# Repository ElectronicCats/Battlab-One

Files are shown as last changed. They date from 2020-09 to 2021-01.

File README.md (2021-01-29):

# BattLab-One
The BattLab-One estimates the battery life of your IOT project using the DUT cutoff voltage, battery state of charge data, event duration, and captured active and sleep event current profiles.

## Main characteristics 

- Captures both active event and sleep mode current

- MSP430 microcontroller based device that simulates standard batteries for Li-Ion, LiFePO4, Alkaline, NiMh, NiCd

- Provides voltages of 1.2V, 1.5V, 2.4V, 3.0V, 3.2, 3.6V, 3.7V, 4.5V at up to 450 mA.

- Trigger input to capture firmware states and their impact on overall battery life

- 1kHz Sample rate, 16 bit delta-sigma ADC

- Long active event capture duration from seconds to hours

- Extremely low burden voltage across all ranges (BattLab-One provides PSU output)

- Provides “what-if” optimization by letting you change your battery, current profiles, active and sleep duration as well as cutoff voltage

- Features the ability to save profiles so you can compare your DUT current profiles

- Interactive/detailed active current plot so you can look for anomalies and identify performance

## Archives
  - Battlab-One Quick Start Guide

  - BattLab_One_Production_Rev_A.py - Python Application Code for Production version 1.01

  - Production_Rev_A.sch - Schematic in Kicad

  - Production_Rev_A.kicad_pcb- PCB Layout in Kicad 

  - MSP430Firmware.c - Firmware code for the MSP430 for Production Version 1.01

  - BOM_Production_Rev_A - Bill of Materials for Battlab-One Production Rev A

  - 98-bluebird-labs.rules - Linux udev rules for Battlab-One

  See more at www.bluebird-labs.com

## Development

This project uses pipenv to take care of setting up a virtual environment as well as managing the dependencies needed.

1. Install pipenv as describe here https://pypi.org/project/pipenv/
2. Start a terminal and change to the root folder of this project.
3. Run pipenv to setup the environment: `pipenv install --dev`
4. Start the pipenv shell: `pipenv shell`
5. Start the application: `python BattLab_One_V1.0.6.py`

## License 

OpenSourceLicense

Electronic Cats invests time and resources providing this open source design, please support Electronic Cats and open-source hardware by purchasing products from Electronic Cats!

Designed by Bluebird Labs LLC

KiCad version Electronic Cats.

Electronic Cats is a registered trademark, please do not use if you sell these PCBs.

January 2021

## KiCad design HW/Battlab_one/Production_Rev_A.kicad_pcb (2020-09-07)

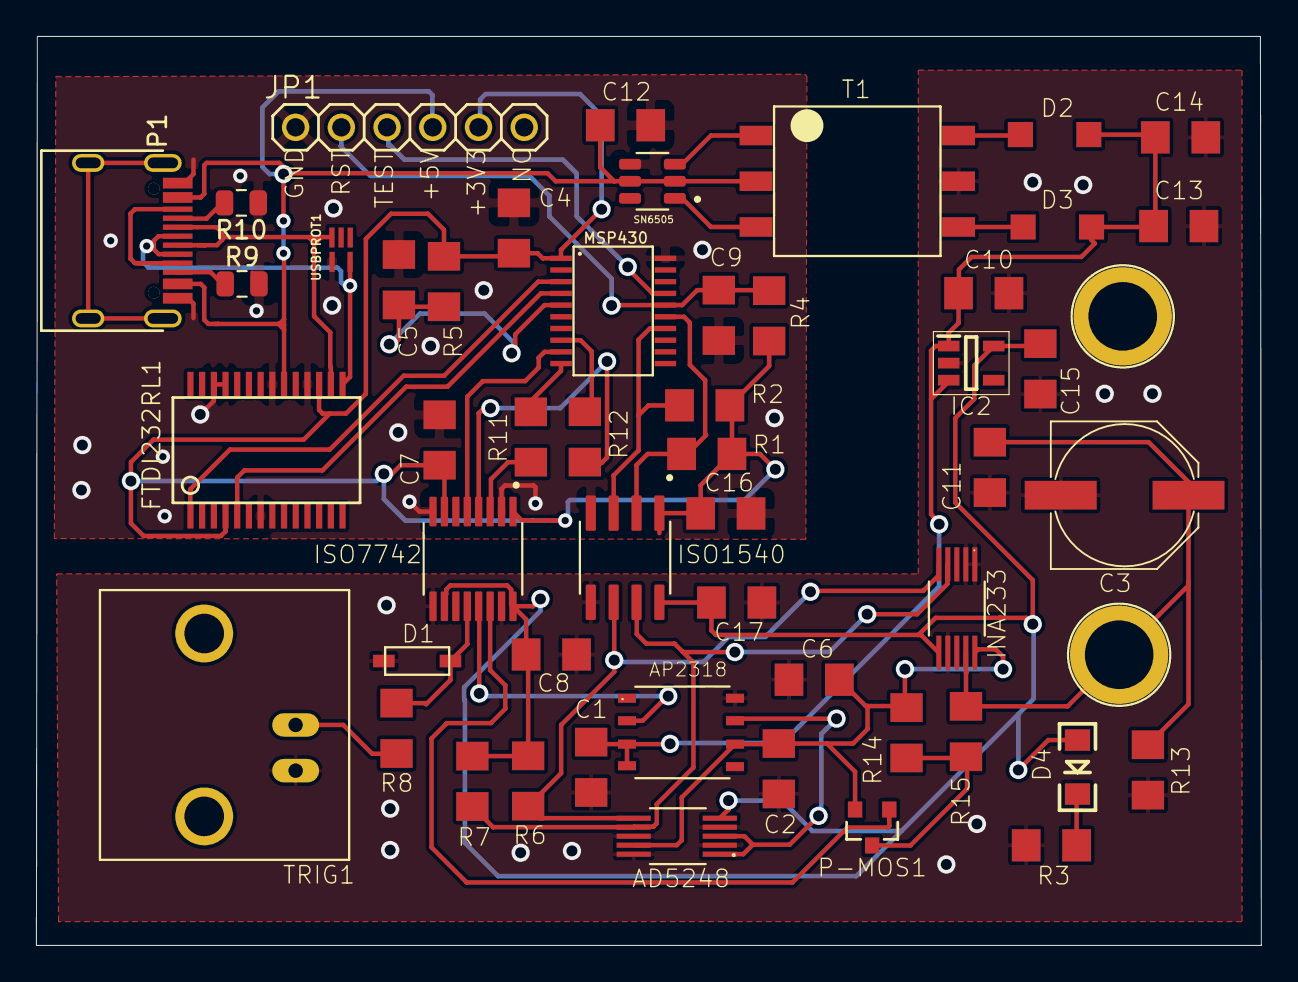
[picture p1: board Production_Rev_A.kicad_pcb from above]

Board: 2 copper layers, 68.1 x 50.5 mm, 53 parts (0 on the bottom side), 37 nets.

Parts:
AD5248: 100K; MSOP-10
AP2318: AP2318; SOIC-8
C1, C4, C10: 1uF; 1206
C2, C6, C15: 2.2uF; 1206
C3: 1000uF; PANASONIC_F
C5: .1uF; 1206
C7, C8, C11, C14, C16, C17: 0.1uF; 1206
C9: 1nF; 1206
C12, C13: 10uF; 1206
D1: DIODESOD-123; SOD-123
D2, D3: MBR0520LT1G; SOD3716X117(SOD-123)
D4: BLUE; LED-1206
FTDI232RL1: FT232RL; SSOP28DB
IC2: MIC5225-5.0YM5-TR; SOT95P280X130-5N
INA233: INA233; VSSOP-10
ISO1540: ISO1540; SOIC127P600X175-8N
ISO7742: ISO7742DBQ; SOP63P599X175-16N
J1, J3: BANANA_CONN
JP1: PINHD-1X6; 1X06
MSP430: MSP430; PW20
P1: USB_C_Plug; C393939
P-MOS1: P-MOSFET; SOT23-3
R1, R2, R6, R7: 10K; 1206
R3: 470; 1206
R4, R5: 47K; 1206
R8, R14: 100; 1206
R9, R10: 5.1K; R_0805_2012Metric
R11, R12: 220; 1206
R13: 100k; 1206
R15: 0.1; 1206
SN6505: SN6505; SOT95P280X145-6N
T1: 750315371; TOR-6P-HT4_SMT_6PIN_(1201)
TRIG1: BNCPTH; BNC
USBPROT1: TPD2E2U06DRLR; SOT50P160X60-5N

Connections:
/D+: FTDI232RL1.15, P1.A6, USBPROT1.5
/D-: FTDI232RL1.16, P1.A7, USBPROT1.3
/VBUS: C12.1, FTDI232RL1.20, JP1.3, P1.A4, SN6505.2, SN6505.5, T1.2
GND: C4.1, C5.1, C7.1, C9.1, C12.2, C16.2, FTDI232RL1.7, FTDI232RL1.18, FTDI232RL1.21, FTDI232RL1.25, FTDI232RL1.26, ISO1540.4, ISO7742.2, ISO7742.8, JP1.6, MSP430.20, P1.A1, R9.2, R10.1, SN6505.4, USBPROT1.4
GND1: AD5248.2, AD5248.4, AD5248.8, AD5248.10, AP2318.8, C1.1, C2.2, C3.-, C6.2, C8.2, C10.2, C11.1, C13.2, C14.2, C15.2, C17.2, D1.A, IC2.2, INA233.1, INA233.2, INA233.7, ISO1540.5, ISO7742.9, ISO7742.15, J3.P$1, R3.1, R13.2, T1.5, TRIG1.GND
unnamed: AD5248.1, AD5248.3, AP2318.7
unnamed: AD5248.5, C8.1, C15.1, C17.1, D4.A, IC2.5, INA233.6, ISO1540.8, ISO7742.10, ISO7742.16, R6.1, R7.1
unnamed: AD5248.6, INA233.5, ISO1540.6, R6.2
unnamed: AD5248.7, INA233.4, ISO1540.7, R7.2
unnamed: AD5248.9, AP2318.6, C2.1, C6.1, INA233.10, P-MOS1.2, R14.1
unnamed: AP2318.2, ISO7742.13
unnamed: AP2318.3, AP2318.4, C1.2, C10.1, C13.1, C14.1, D2.1, D3.1, IC2.1, IC2.3
unnamed: C5.2, MSP430.5, R5.1
unnamed: C9.2, JP1.5, MSP430.16, R4.2
unnamed: C3.+, C11.2, INA233.9, J1.P$1, R13.1, R15.2
unnamed: C4.2, C7.2, C16.1, FTDI232RL1.4, FTDI232RL1.17, ISO1540.1, ISO7742.1, ISO7742.7, JP1.2, MSP430.1, R1.2, R2.2, R4.1, R5.2
unnamed: D1.C, ISO7742.12, R8.2
unnamed: D2.2, T1.6
unnamed: D3.2, T1.4
unnamed: D4.C, R3.2
unnamed: FTDI232RL1.1, MSP430.3
unnamed: FTDI232RL1.5, MSP430.4
unnamed: ISO1540.2, MSP430.15, R1.1
unnamed: ISO1540.3, MSP430.14, R2.1
unnamed: ISO7742.3, R11.2
unnamed: ISO7742.4, R12.2
unnamed: ISO7742.5, MSP430.9
unnamed: ISO7742.14, P-MOS1.1
unnamed: JP1.4, MSP430.17
unnamed: MSP430.8, R12.1
unnamed: MSP430.10, R11.1
unnamed: P1.A5, R10.2
unnamed: P1.B5, R9.1
unnamed: P-MOS1.3, R14.2, R15.1
unnamed: R8.1, TRIG1.S
unnamed: SN6505.1, T1.3
unnamed: SN6505.3, T1.1

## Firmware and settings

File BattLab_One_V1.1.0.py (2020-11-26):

#################################################################################
##   MSP430G2xx3 based BattLab-One Production Version 1.01
##
##   Doug Peters
##   Bluebird Labs LLC.
##   www.bluebird-labs.com
##   February 2019
##   Built with CCS V7.0
##
##   Copyright (c) 2020, Bluebird Labs LLC
##   All rights reserved.
##
##   Redistribution and use in source and binary forms, with or without
##   modification, are permitted provided that the following conditions
##   are met:
##
##   * Redistributions of source code must retain the above copyright
##     notice, this list of conditions and the following disclaimer.
##
##   * Redistributions in binary form must reproduce the above copyright
##     notice, this list of conditions and the following disclaimer in the
##     documentation and/or other materials provided with the distribution.
##
##   * Neither the name of Bluebird Labs LLC nor the names of
##     its contributors may be used to endorse or promote products derived
##     from this software without specific prior written permission.
##
##  THIS SOFTWARE IS PROVIDED BY THE COPYRIGHT HOLDERS AND CONTRIBUTORS "AS IS"
##  AND ANY EXPRESS OR IMPLIED WARRANTIES, INCLUDING, BUT NOT LIMITED TO,
##  THE IMPLIED WARRANTIES OF MERCHANTABILITY AND FITNESS FOR A PARTICULAR
##  PURPOSE ARE DISCLAIMED. IN NO EVENT SHALL THE COPYRIGHT OWNER OR
##  CONTRIBUTORS BE LIABLE FOR ANY DIRECT, INDIRECT, INCIDENTAL, SPECIAL,
##  EXEMPLARY, OR CONSEQUENTIAL DAMAGES (INCLUDING, BUT NOT LIMITED TO,
##  PROCUREMENT OF SUBSTITUTE GOODS OR SERVICES; LOSS OF USE, DATA, OR PROFITS;
##  OR BUSINESS INTERRUPTION) HOWEVER CAUSED AND ON ANY THEORY OF LIABILITY,
##  WHETHER IN CONTRACT, STRICT LIABILITY, OR TORT (INCLUDING NEGLIGENCE OR
##  OTHERWISE) ARISING IN ANY WAY OUT OF THE USE OF THIS SOFTWARE,
##  EVEN IF ADVISED OF THE POSSIBILITY OF SUCH DAMAGE.
##
#################################################################################

import tkinter as tk
from tkinter import ttk
from tkinter import *
import csv
from csv import reader
import time
import datetime
import serial
import serial.tools.list_ports
from serial.tools import list_ports
import matplotlib
from matplotlib.widgets import Cursor
import matplotlib.pyplot as plt
import platform
from tkinter import colorchooser
from tkinter import font
import os
import pkg_resources.py2_warn
from tkinter import messagebox
from tkinter import filedialog
import webbrowser

matplotlib.use('TkAgg')

#from matplotlib.backends.backend_tkagg import FigureCanvasTkAgg, NavigationToolbar2TkAgg
from matplotlib.backends.backend_tkagg import FigureCanvasTkAgg, NavigationToolbar2Tk
from matplotlib.figure import Figure

#################################################################################    
###     SETUP ROOT, FRAMES, & MATPLOTLIB CANVAS
#################################################################################

def GetIconPath():
   if platform.system() == 'Linux':
      return '@icons\\bbirdlogo.xbm'
   else:
      return 'icons\\bbirdlogo.ico'

root = tk.Tk()
root.wm_title('BattLab One')
root.resizable(False,False)
root.grid_rowconfigure(0, weight=1)
root.grid_columnconfigure(0, weight=1)

#root.iconbitmap('bbirdlogo.ico')
root.iconbitmap(GetIconPath())

s = ttk.Style() 
s.configure('TLabelframe', background='dark gray')

profile_frame = ttk.Frame(root,style='TLabelframe', width = 800, height = 600)
profile_frame.grid(row=0, column=0, padx=5,pady=(1,1),sticky = 'n')

def openBBL():
   webbrowser.open_new('http://bluebird-labs.com')

#img = PhotoImage(file='bbirdlogo_png1.png')
img = PhotoImage(file='icons\\bbirdlogo_png1.png')

logo_button = tk.Button(profile_frame,image=img,command=openBBL,state=tk.NORMAL)
logo_button.grid(row=27,column=0,rowspan=4, padx=(5,4),pady=(5,5),sticky = 'sw')

frame = ttk.Frame(profile_frame, borderwidth=5, relief='sunken', width=800, height=450)
frame.grid(row=0, column=1,  rowspan=20, padx=(3,10),pady=(1,1), sticky='n')

frame1 = ttk.Frame(profile_frame, borderwidth=5, relief='sunken', width=800, height=600)
frame1.grid(row=20, column=1, rowspan=10, padx=(10,10),pady=(5,15), sticky='e')

w = Canvas(frame, width=800, height=400)
w.config(background='black')
w.grid(row=0,column = 3,padx=5,pady=(5,5),sticky = 'n')

w1 = Canvas(frame1, width=250, height=200)
w1.config(background='black')
w1.grid(padx=5,pady=(5,5),sticky = 'nsew')

#################################################################################
###   SETUP GLOBAL VARIABLES
#################################################################################
global si,x,y, avg_active_event_I, line_color, sleep_timer,soc_file

x = []
y = []
si = []
soc = []
ocv = []
esr = []
soc_tab = []
ocv_tab = []
esr_tab = []
dc = []
dc1 = []

lo_offset=tk.DoubleVar()
lo_offset.set(0)

sleep_timer=tk.IntVar()
sleep_timer.set(1)

LSB=0.0025

line_color = StringVar()
line_color.set("blue")

line_width = DoubleVar()
line_width.set(0.5)

reading = StringVar()

CAL_12_data = StringVar()
CAL_15_data = StringVar()
CAL_24_data = StringVar()
CAL_30_data = StringVar()
CAL_36_data = StringVar()
CAL_37_data = StringVar()
CAL_42_data = StringVar()
CAL_45_data = StringVar()

Offset_12_data = StringVar()
Offset_15_data = StringVar()
Offset_24_data = StringVar()
Offset_30_data = StringVar()
Offset_36_data = StringVar()
Offset_37_data = StringVar()
Offset_42_data = StringVar()
Offset_45_data = StringVar()

sense_resistor = tk.DoubleVar()
sense_resistor.set(0.160)

sense_resistor_LO = tk.DoubleVar()
sense_resistor_LO.set(99)

data = tk.StringVar()
version = tk.StringVar()

soc_file = tk.StringVar()
soc_file.set('SOC_profiles/AA_AAA.csv')

samples= tk.IntVar()
samples.set(4)

#################################################################################
###   GET SERIAL PORT AND CONNECT
#################################################################################

baud_rate = 115200
com_port = "NONE"

def get_ports():
   ports = list(serial.tools.list_ports.comports())
   cpl = []
   for p in ports:
      cpl.append(p.device)   
   return cpl

def popupmsg(msg):
    popup = tk.Tk()
    #popup.iconbitmap('bbirdlogo.ico')
    popup.iconbitmap(GetIconPath())
    popup.wm_title("About")
    label = ttk.Label(popup, text=msg,)
    label.grid(row=0,column=0, padx=(10,10),pady= (10,10),sticky = 'nsew')
    pop_up_button = tk.Button(popup, text="Okay",command = popup.destroy,state=tk.NORMAL)
    pop_up_button.grid(row=3,column=0,padx=30,pady=(10,10),sticky = 'w')
    popup.mainloop()
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

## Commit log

2020-09-07 Eagle imported
    [Production_Rev_A.kicad_pcb, Production_Rev_A.sch]
2020-09-07 Type-C Usb and footprint assigned.
2020-09-07 USB-C resistor
    [Production_Rev_A.kicad_pcb, Production_Rev_A.sch]
2020-09-07 paht for eagle
    [BOM_Production_Rev_A (2).xlsx, Production_Rev_A.brd, Production_Rev_A.sch]
2020-09-07 Usb c fixed RTC 0 unconnect
    [Production_Rev_A.kicad_pcb]
2020-09-07 Silkscreen moved
    [Production_Rev_A.kicad_pcb, Production_Rev_A.sch]
2020-11-27 Added component
    [Production_Rev_A.sch]
2020-12-14 Added other "FTDI" component
    [Production_Rev_A.sch]
2021-01-29 erased eagle files
    [BOM_Production_Rev_A (2).xlsx, Production_Rev_A.brd, Production_Rev_A.sch]
